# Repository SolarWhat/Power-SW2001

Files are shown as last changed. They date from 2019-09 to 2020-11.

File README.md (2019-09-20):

# Power-SW2001

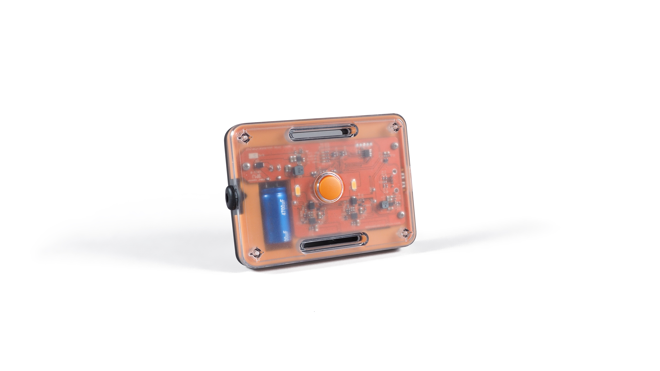
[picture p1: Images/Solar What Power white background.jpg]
Solar What?! Power Hero Image


Solar What?! is the outcome of ongoing research at the University of Edinburgh.

The product design process has taken place over three continents, with input from solar technicians, end users and energy access practitioners.

In 2017 over 6 million small, solar powered lighting devices were sold worldwide and 1.6 million solar powered lighting devices entered electronic waste flows.

We believe that delivering affordable, clean energy for all can also promote responsible production and consumption.

Our goal is to advocate for sustainable design in the global solar industry and promote the repair, reuse and recycling of solar powered electronics. We are pro-solar, anti-waste.

The Solar What?! Power is one of two products we have designed to champion our research and catalyse discussion around sustainability and repairability in the off-grid solar sector. The repository for our other product, the Solar What Light, can be found [here](https://github.com/SolarWhat/Light-SW1001 "here").

We encourage you to download the files, reproduce the products, make edits, suggest improvements and, most importantly, share your ideas around design for sustainable international development.  

More information about the project and the team behind it can be found on our [website](http://www.solarwhat.xyz/index.php "website").

You can get in touch with the team by emailing info@solarwhat.xyz. 

[User Manual and Tech Specs](http://www.solarwhat.xyz/resources.php "User Manual and Tech Specs")

[Gerber Files, BOM and Firmware Files](https://github.com/SolarWhat/Power-SW2001/tree/master/PCB%20Files "Gerber Files, BOM and Firmware Files")

[CAD Files (stp)](https://github.com/SolarWhat/Power-SW2001/blob/master/Solar%20What%20Power%20Assembly.stp "CAD Files (stp)")

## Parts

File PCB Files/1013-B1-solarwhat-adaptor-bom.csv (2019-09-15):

Component | Value | Manufacturer Part Number | Supplier Part Number | Description | Notes
C1 |  | Panasonic ECA1VAM472X | Farnell 8767327
C2 | 1206-10U-35V 10u 35V | 1206 10uF 35V 10% X7R | standard
C3 | 1206-10U-35V 10u 35V | 1206 10uF 35V 10% X7R | standard
C4 | 0805-1U 1u | 0805 1uF 50V 10% X7R | standard
C5 | 0603-100N 100n | 0603 100nF 50V 10% X7R | standard
C6 | 1206-10U-35V 10u 35V | 1206 10uF 35V 10% X7R | standard
C7 | 1206-10U-35V 10u 35V | 1206 10uF 35V 10% X7R | standard
C8 | 1206-10U-35V 10u 35V | 1206 10uF 35V 10% X7R | standard
C9 | 1206-10U-35V 10u 35V | 1206 10uF 35V 10% X7R | standard
C10 | 1206-10U-35V 10u 35V | 1206 10uF 35V 10% X7R | standard
C11 | 1206-10U-35V 10u 35V | 1206 10uF 35V 10% X7R | standard
C12 | 1206-10U-35V 10u 35V | 1206 10uF 35V 10% X7R | standard
C13 | 0603-100N 100n | 0603 100nF 50V 10% X7R | standard
C14 | 1206-10U-35V 10u 35V | 1206 10uF 35V 10% X7R | standard
C15 | 0603-100N 100n | 0603 100nF 50V 10% X7R | standard
C16 | 1206-10U-35V 10u 35V | 1206 10uF 35V 10% X7R | standard
C17 | 1206-10U-35V 10u 35V | 1206 10uF 35V 10% X7R | standard
D1 |  | Cree JB5630AWT-C0-0000-000A0UC430E | Farnell 2853292
D2 |  | Cree JB5630AWT-C0-0000-000A0UC430E | Farnell 2853292
D3 |  | ST STPS1L30U | Farnell 1467550
D4 |  | Vishay VS-10BQ060-M3 | Farnell 2628281
D5 |  | ST STPS1L30U | Farnell 1467550
D6 |  | Red 0603 LED | Farnell 2687488
D7 |  | RB751S40T1G | Farnell 2317437
D8 |  | Green 0603 LED | Farnell 2687486
D9 |  | RB751S40T1G | Farnell 2317437
D10 |  | Green 0603 LED | Farnell 2687486
D11 |  | Orange 0603 LED | Farnell 2687484
D12 |  | RB751S40T1G | Farnell 2317437
D13 |  | RB751S40T1G | Farnell 2317437
D14 |  | RB751S40T1G | Farnell 2317437
D15 |  | RB751S40T1G | Farnell 2317437 |  | fit reversed relative to markings on board revision 1013-B!
D16 |  | RB751S40T1G | Farnell 2317437 |  | fit reversed relative to markings on board revision 1013-B!
J1 |  | Multicomp MC32593 | Farnell 1696534
J2 |  | CamdenBoss CTBP0508/2 | Farnell 2668641
JP1 |  | SOLDER-JUMPER-2MM SOLDER-JUMPER-2MM | - |  | connect
JP2 |  | SOLDER-JUMPER-2MM SOLDER-JUMPER-2MM | - |  | connect
JP3 |  | SOLDER-JUMPER-2MM SOLDER-JUMPER-2MM | - |  | connect
L2 | TDK-VLSX6045EX-220M 22uH | VLS6045EX-220M | Farnell 2493045
L3 | TDK-VLSX5045EX-3R3N 3.3uH | TDK VLS5045EX-3R3N | Farnell 2776741
Q1 |  | Diodes Inc DMP2035U | Farnell 2061419
Q2 |  | Diodes Inc DMP2035U | Farnell 2061419
Q3 |  | Diodes Inc DMP2035U | Farnell 2061419
Q4 |  | Diodes Inc DMP2035U | Farnell 2061419
Q5 |  | Diodes Inc DMP2035U | Farnell 2061419
R1 | 0603-1%-1M 1M | 0603 1M 1% 100mW | standard
R2 | 0603-1%-56K 56K | 0603 56K 1% 100mW | standard
R3 | 0603-1%-10K 10K | 0603 10K 1% 100mW | standard
R4 | 0603-1%-100K 100K | 0603 100K 1% 100mW | standard
R5 | 0603-1%-270K 270K | 0603 270K 1% 100mW | standard
R6 | 0603-1%-2K2 2K2 | 0603 2.2K 1% 100mW | standard
R7 | 0603-1%-47K 47K | 0603 47K 1% 100mW | standard
R8 | 0603-1%-100K 100K | 0603 100K 1% 100mW | standard
R9 | 0603-1%-270K 270K | 0603 270K 1% 100mW | standard
R10 | 0603-1%-2K2 2K2 | 0603 2.2K 1% 100mW | standard
R11 | 0603-1%-100K 100K | 0603 100K 1% 100mW | standard
R12 | 0603-1%-100K 100K | 0603 100K 1% 100mW | standard
R13 | 0603-1%-680K 680K | 0603 680K 1% 100mW | standard
R14 | 0603-1%-100K 100K | 0603 100K 1% 100mW | standard
R15 | 0603-1%-47R 47R | 0603 47R 1% 100mW | standard
R16 | 0805 11R | 0805 11R 1% 100mW | standard
R17 | 0805 1R6 | 0805 1R6 1% 100mW | standard
R18 | 0805 1R6 | 0805 1R6 1% 100mW | standard
R19 | 0603-1%-75K 75K | 0603 75K 1% 100mW | standard
R20 | 0603-1%-49K9 49K9 | 0603 49K9 1% 100mW | standard
R21 | CHIP-0603-DNF DNF |  |  |  | Do Not Populate
R22 | 0603-1%-75K 75K | 0603 75K 1% 100mW | standard
R23 | 0603-1%-49K9 49K9 | 0603 49K9 1% 100mW | standard
R24 | 0603-1%-110K 110K | 0603 110K 1% 100mW | standard
R25 | 0603-1%-1M 1M | 0603 1M 1% 100mW | standard
R26 | 0603-1%-470K 470K | 0603 470K 1% 100mW | standard
R27 | NTC-0603-10K 10K | NCP18XH103F03RB 10K NTC Thermistor | Farnell 2456122
R28 | 0603-1%-470K 470K | 0603 470K 1% 100mW | standard
R29 | NTC-0603-10K 10K | NCP18XH103F03RB 10K NTC Thermistor | Farnell 2456122
R30 | 0603-1%-4K7 4K7 | 0603 4.7K 1% 100mW | standard
R31 | 0603-1%-220R 220R | 0603 220R 1% 100mW | standard
R32 | 0603-1%-220R 220R | 0603 220R 1% 100mW | standard
R33 | 0603-1%-220R 220R | 0603 220R 1% 100mW | standard
R34 | 0603-1%-1M 1M | 0603 1M 1% 100mW | standard
R35 | 0603-1%-220R 220R | 0603 220R 1% 100mW | standard
R36 | 0603-1%-1M 1M | 0603 1M 1% 100mW | standard
R37 | 0603-1%-1M 1M | 0603 1M 1% 100mW | standard
R38 | 0603-1%-1M 1M | 0603 1M 1% 100mW | standard
R39 | 0603-1%-1M 1M | 0603 1M 1% 100mW | standard
R40 | 0603-1%-1M 1M | 0603 1M 1% 100mW | standard
R41 | 0603-1%-1M 1M | 0603 1M 1% 100mW | standard
R42 | CHIP-0603-DNF DNF |  |  |  | Do Not Populate
R43 | CHIP-0603-DNF DNF |  |  |  | Do Not Populate
R44 | 0603-1%-0R 0R | 0603 0R 1% 100mW | standard
R45 | 0603-1%-0R 0R | 0603 0R 1% 100mW | standard
R46 | 0603-1%-0R 0R | 0603 0R 1% 100mW | standard
R47 | 0603-1%-1M 1M | 0603 1M 1% 100mW | standard
R48 | 0603-1%-1M 1M | 0603 1M 1% 100mW | standard
R49 | 0805 11R | 0805 11R 1% 100mW | standard
R50 | 0603-1%-47R 47R | 0603 47R 1% 100mW | standard
SW1 |  | Alcoswitch FSM4JSMA | Farnell 3801305
U1 |  | Microchip MCP16311T-E/MS | Farnell 2857601
U2 |  | MCP73871-2CCI/ML | Farnell 1642489
U3 |  | TI TPS63030 | Farnell 2781754
U4 |  | MCP73871-2CCI/ML | Farnell 1642489
U5 |  | Microchip PIC12F1571-I/SN | Farnell 2419682
U6 |  | MCP1824-ADJ SOT-23-5 | Farnell 1578393
U7 |  | MAX6775XKB+T | Farnell 2799268
U8 |  | MAX6775XKB+T | Farnell 2799268
XBT1 |  | AVX 009155003301006 | Digi-key 478-4687-1-ND
XBT2 |  | AVX 009155003301006 | Digi-key 478-4687-1-ND

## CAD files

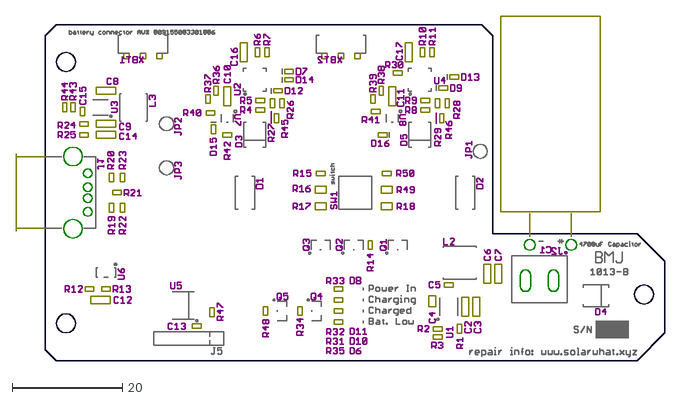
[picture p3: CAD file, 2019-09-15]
PCB Files/1013-B-solarwhat-power-dimensions.dxf
117.8 x 62.5

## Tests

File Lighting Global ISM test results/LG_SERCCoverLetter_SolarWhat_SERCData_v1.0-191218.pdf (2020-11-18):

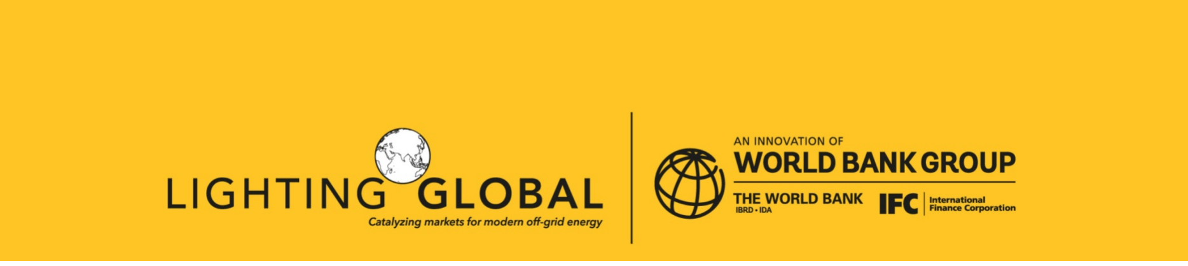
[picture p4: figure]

Lighting Global Quality Test Method Results | 1
Lighting Global Quality Assurance | © Lighting Global 2019

18 December 2019

### Lighting Global Internal Screening Test Method Results: SOLAR WHAT?!

To: Rowan Spear
University of Edinburg
Social Anthropology Chrystal Macmillan Bldg. 15A, George Square, Edinburgh, EH89LD Rowan.spear@ed.ac.uk
From: Lighting Global Quality Assurance Team

We recently received Lighting Global Initial Screening Method (LG-ISM) results for the Solar What?!. The tests were completed at the Schatz Energy Research Center in Arcata, California, and include performance, quality, and attribute measurements. This letter is a summary of the results detailed in the test report, number SERC19002ISM. The three samples arrived at the test lab on 18 August 2019. The sampling report can be provided upon request.

The results indicate that it is likely that your product would not meet the Lighting Global Pico-PV Quality Standards.
1 The reasons the product would likely not meet the standards include issues identified during testing related to truth in advertising, ports, performance reporting, warranty, screw terminals, and water ingress protection. Additional testing according to the Quality Test Method (QTM) procedures described in IEC Technical Specification 62257-9-5 is needed to make an official determination regarding the status of the product in relation to the Lighting Global Quality Standards.
The Lighting Global Pico-PV Quality Standards, which are required for basic program participation, include:
- Truth in Advertising, Performance Reporting and Warranty: Accurate consumer-facing labeling and basic 1-year warranty
- Lumen Maintenance: Average lumen output after 2000 hours of use ≥ 90% initial output or average lumen output after 1000 hours of use ≥ 95% initial output
- Quality: Pass basic durability, safety, and quality checks
- Ingress Protection: Physical ingress protection of IP 2x or greater (IP 3x for separate solar modules and IP 5x for permanently mounted outdoor products)
- Water Protection: Protection from permanent outdoor exposure for outdoor products, frequent rain for portable products with integrated solar modules, and occasional rain for other portable products
- Battery Protection: Protection by an appropriate charge controller that prolongs battery life and protects the safety of the user

Lighting Global Quality Test Method Results | 2
Lighting Global Quality Assurance | © Lighting Global 2019
- Battery Durability: Average battery storage capacity loss ≤ 25% after storage under adverse conditions and no more than one unit of the units tested may have a capacity loss greater than 35%
- Performance Reporting Requirements: Accurately report the product’s light output and solar run time performance for its brightest setting, and if applicable, include a statement regarding the impact of mobile phone charging and/or radio use on the lighting run time

We are providing these test results to you confidentially as a service to your organization so that you can use them to further improve your product. Page 9 contains a list of next steps that will help you to address these issues. Lighting Global does not plan to release the name of your product in conjunction with these results, although we may choose to publish results or derivative analyses in a way that does not reveal the identity of the product. The following is a summary of the test results, drawing from the official test reports that are attached to this letter.

Lighting Global Quality Test Method Results | 3
Lighting Global Quality Assurance | © Lighting Global 2019

## SOLAR WHAT?! Results Summary

Quality Standards

Aspect | Requirement | Results | Notes / Suggested Compliance Actions
Truth in Advertising | Accurate | The full-battery run time for the SW2001 on its high setting is rated 6 h on the product’s website but measured 4.9 h (-18%) The full-battery run time for the SW2001 on its low setting is rated 96 h on the product’s website but measured 53 h (-45%) | Correct the ratings on the website / packaging or change the design of the system to match the ratings.
Ports | Ports must be accurately advertised and meet voltage requirements | The USB Port did not meet the truth-in-advertising or functionality requirements. | Improve the regulation of the 5 V port. See Required Steps for Compliance section for details.
Performance Reporting Requirements | Report light output and solar run time, and include a mobile phone charging statement | The performance reporting for the product could not be evaluated because packaging was not provided. | Provide product packaging for evaluation.
Warranty | 1 year | The warranty could not be evaluated because no warranty information was provided. | Provide a detailed warranty in a consumer-facing location
Lumen Maintenance | L95 or greater at 500 hours | OK | OK
Quality Check | Functionality, wiring, soldering, cables | OK | OK
Circuit and Overload Protection | Sufficient overcurrent and overload protection | OK | OK
Wiring and Connector Safety | Manufacturer declares wires are appropriately sized | OK, with note | Products undergoing QTM testing are required to submit a Lighting Global Off-Grid Product Testing Declaration Form

Lighting Global Quality Test Method Results | 4
Lighting Global Quality Assurance | © Lighting Global 2019
Battery Protection | Protect battery and user Provide safety documentation | OK, with note | Products undergoing QTM testing are required to submit battery safety documentation.
Battery Durability | 25% or less capacity loss, no more than one greater than 35% capacity loss | OK | OK
PV Overvoltage Protection | Sufficient protection from PV voltage when battery removed | OK | OK
Miswiring Protection | Product design sufficiently protects from misconnections | OK | OK
Drop Test Durability | Functionality, safety | OK | OK
Switch, Connector, and Strain Relief Durability | Functionality, safety | OK | OK
Screw Terminal | Adequate tools, materials, and instructions provided, and safety | Adequate instructions are not provided for non-plug and play connections | Provide additional instruction for the non-plug and play connections in a consumer-facing location.
Water Exposure Protection | SW2001:Occasional rain or equivalent | The product does not meet IPX1 and does not have an adequate warning label for ingress protection. | Improve the level of water protection. See Required Steps for Compliance section for details.
| PV module: Permanent outdoor exposure or equivalent | OK | OK
| SW001: Occasional rain or equivalent | The torch does not meet IPX1 and does not have an adequate warning label for ingress protection. | Improve the level of water protection. See Required Steps for Compliance section for details.
Physical Ingress Protection | SW2001 and SW1001: IP 2x | OK, with note | The SW2001 met IP3X and the SW1001 met IP4X
| PV module: IP3x | OK | OK

Lighting Global Quality Test Method Results | 5
Lighting Global Quality Assurance | © Lighting Global 2019

Product Comparison
The box plots below show how the Solar What ?! performs compared to other products that have been tested through the Lighting Global program within the past year for the following metrics:.
Lighting
- lumen maintenance – fraction of total light output remaining after 2000 hours of continuous use
- lumen efficacy – total light output divided by the power consumed by the system
- correlated color temperature – measure of the color appearance of the light; low values are considered warmer and higher values cooler
- color rendering index – measure of the light’s ability to reveal colors on illuminated surfaces
Battery
- battery efficiency – fraction of the energy delivered to the battery during charging that is recovered during use
- battery capacity loss – fraction of the battery capacity irreversibly lost due to degradation of the battery after a simulated six-month storage period
Ports and Charging
- ports efficiency – fraction of energy from the appliance port that is delivered to the appliance when powered on
- solar operation efficiency – ratio of the energy produced by the solar module during a typical day of solar charging to the energy that could be produced (i.e., if the module operated at the maximum power point at all times)
- charging efficiency – fraction of the energy input into the charging port that is delivered to the battery
In each box plot, the center horizontal line represents the median value of the performance metric for products that have been tested within the past year. The box includes the values between the first and third quartiles (i.e., the middle 50%). The ends of the whiskers show the minimum and maximum values observed. The red X represents the Solar What?!’s performance.

Lighting Global Quality Test Method Results | 6

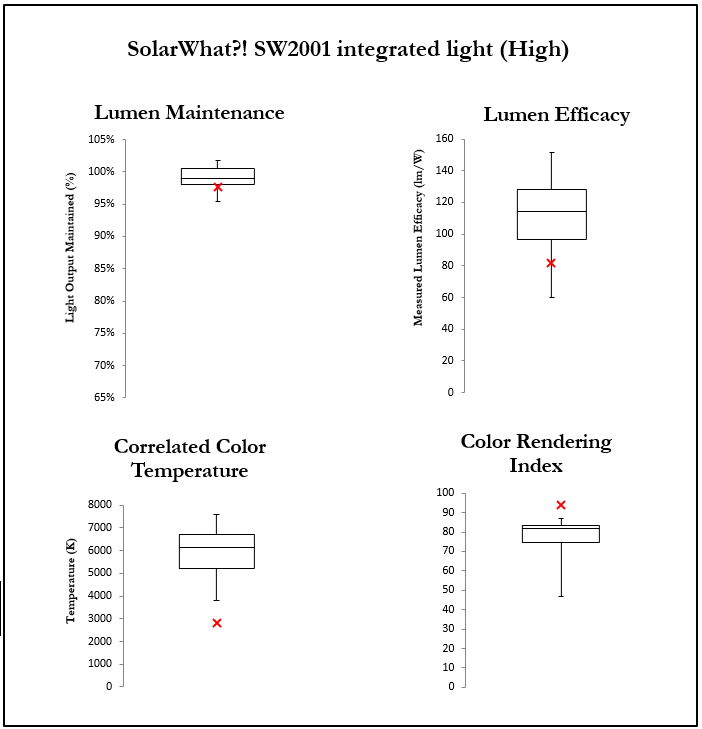
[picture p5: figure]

Lighting Global Quality Assurance | © Lighting Global 2019

Lighting Global Quality Test Method Results | 7

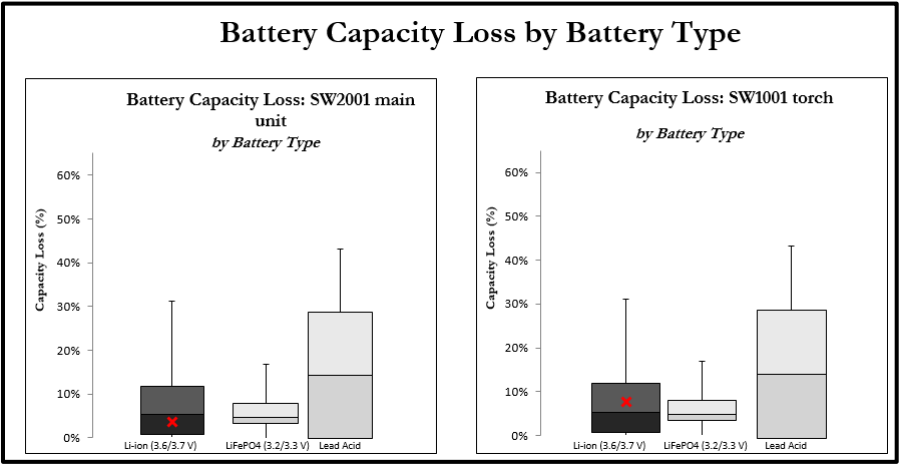
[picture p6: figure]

Lighting Global Quality Assurance | © Lighting Global 2019
- The lumen efficacy of the Solar What?! SW2001 is notably low compared to other products that have been tested through the Lighting Global program within the past year. A lower lumen efficacy indicates that your product’s LED and driver require more power to provide light compared to other products tested. You may consider improving the energy efficiency of the main control unit and light bulbs. This could allow the product to provide a brighter light or longer run time using the existing solar module and battery.
- The correlated color temperature (CCT) of the Solar What?! SW2001 is notably low compared to other products that have been tested through the Lighting Global program within the past year. A lower CCT indicates that the light produced by your product is warmer (more red) compared to other products tested. Consumer preferences regarding light color vary, and there is no consensus on the ideal CCT value for off-grid solar lamps. Nonetheless, some market studies indicate that many consumers prefer products with lower CCT values (i.e. warmer light). Research regarding CCT and eye safety indicates that very bright lights with high CCT can increase the risk of hazard to the human eye. See Lighting Global Eco-Design Notes Issue 5: LED Lights and Eye Safety Part II: Blue light hazards via www.lightingglobal.org/resources/?fwp_resource_type=eco-design-notes.
- The color rendering index (CRI) of the Solar What?! SW2001 is notably high compared to other products that have been tested through the Lighting Global program within the past year. A higher CRI indicates that your product’s LED package is able to reveal colors better compared to other products tested; that is, colors more closely resemble their appearance under daylight or an incandescent lamp.

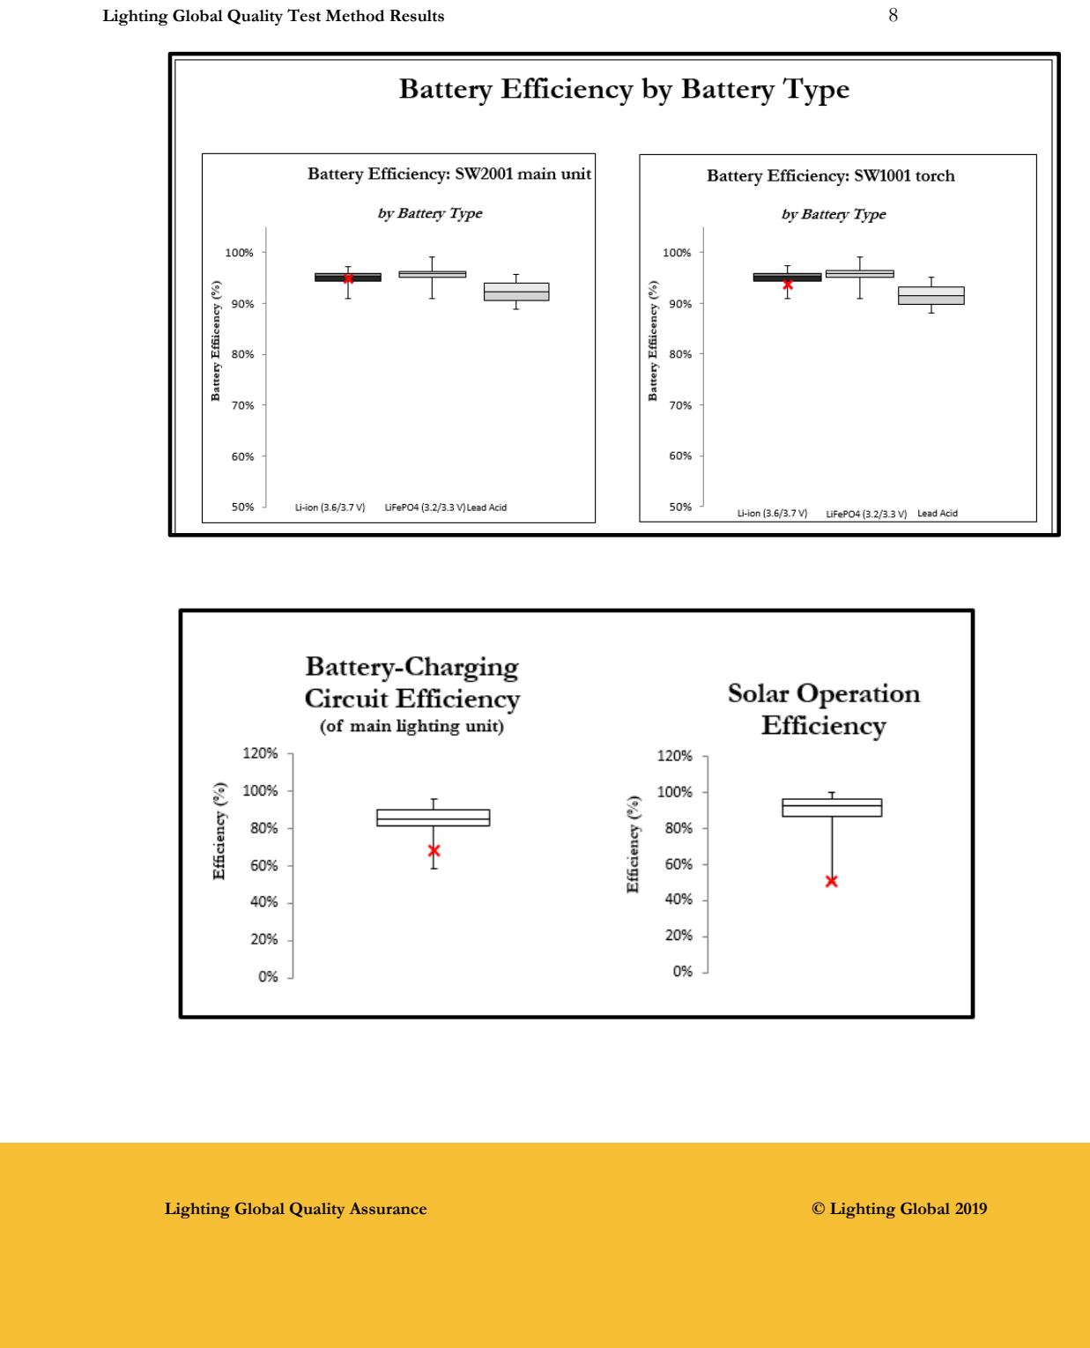
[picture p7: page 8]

Lighting Global Quality Test Method Results | 8
Lighting Global Quality Assurance | © Lighting Global 2019

Lighting Global Quality Test Method Results | 9
Lighting Global Quality Assurance | © Lighting Global 2019
- The battery-charging circuit efficiency of the Solar What?! SW2001 is notably low compared to other products that have been tested through the Lighting Global program within the past year. A lower charging efficiency indicates that the charging circuitry within the product, delivering energy from the generator to the battery, is less efficient than other products tested.
- The solar operation efficiency of the Solar What?! is notably low compared to other products that have been tested through the Lighting Global program within the past year. A lower solar operation efficiency indicates that your product is less effectively utilizing its solar module compared to other products tested. Product Strengths
- The product is well constructed, and the workmanship is good.
- The Solar What?! maintains its luminous output over 500 hours of continuous use.
- The housing appears to be sturdy.

Required Steps for Compliance
- Properly rate the product’s full-battery run time in all consumer-facing locations. The full-battery run time for the SW2001 on its high setting is rated 6 h on the product’s website but measured 4.9 h (-18%). The full-battery run time for the SW2001 on its low setting is rated 96 h on the product’s website but measured 53 h (-45%).
- Properly rate the current of the USB port. Currently the port is rated to deliver up to 5 A, but the measured maximum current was 0.36 A.
- Include a consumer-facing warranty of at least 1 year for all product components, including the product’s battery. The warranty must include information regarding the terms of the warranty and how to access the warranty. Details of the warranty requirements are available here: http://www.lightingglobal.org/resource/performance-reporting-requirements/
- Improve the voltage regulation of the USB ports. These ports must meet the voltage requirements listed in footnote d of the Pico PV Quality Standards. The product does not meet the Standard for USB port functionality because its USB port voltage is outside the allowable thresholds. The Standards require that the USB port not fall below 4.5 V and never exceed 5.5 V under all test conditions, except the deep discharge protection voltage (USB voltages of 4.25 V are permitted when the product’s battery has reached the deep discharge protection cutoff). The Solar What’s USB port voltage falls below the proposed requirement; falling to 4.37 V. The current for the USB port is rated 0.5 A, but measured 0.36 and therefore does not meet the truth-in-advertising requirement for ports. Redesign the port regulation so that it functions within the allowable threshold at high battery voltages.
- Improve the level of water protection for the SW1001 and the SW2001. As portable separate products, the product must have water protection against occasional rain. This could be achieved using one of three options:
- Meet IPX1 – vertical water drip. This could be done by adding gaskets, improving jack positioning, covering jacks, and/or reducing manufacturing tolerances.
- Include an appropriate consumer-facing warning label to keep the product from water exposure. The warning label must explain the degree of protection from water provided by the product (e.g., “Designed for indoor use”) AND steps a consumer should take to prevent water exposure and to drain or dry the product (e.g., “Protect the product from exposure to water. If the product gets wet, …”)
- OR include a technical level of water protection, such as a conformal coating and a proper water removal strategy.

Lighting Global Quality Test Method Results | 10
Lighting Global Quality Assurance | © Lighting Global 2019
- Report the product’s light output and solar run time for the brightest setting and include a statement regarding the impact of mobile phone charging on lighting run time on the product packaging. Detailed guidelines are described in the Performance Reporting Requirements Policy here: http://www.lightingglobal.org/resource/performance-reporting-requirements/
- The product does not meet the requirements for screw terminals for the following reasons:
- Adequate instructions for making the connections, a list of required tools, information regarding the type of battery and size of PV module to be used with the product, and adequate description for identifying wires to avoid incorrect connections were not provided in writing with the product. This information is provided in the on-line user manual, but must be available in writing in order to meet the requirements.
- There are no evident physical barriers on the screw terminal block to prevent short-circuiting the PV leads. The Lighting Global Standards require short circuit protection for the leads from the battery to PV module.
- There is no statement reporting that the terminals are for indoor use only provided in writing nor provided on the product’s website.
Next Steps
- Because the ISM results indicate that the Solar What?! is unlikely meet the Quality Standards, we
recommend that you take action to bring your product in line with the Quality Standards. The key points of failure for not meeting the Quality Standards are summarized above. Once these changes have been made, we suggest you coordinate with the Lighting Global Quality Assurance Team to submit the Solar What?! for testing according to the Quality Test Method (QTM) approach.

In addition, Lighting Global has produced a series of technical notes and eco design notes on off-grid lighting that you may find helpful going forward; they are available at: http://www.lightingglobal.org/resources/?fwp_resource_type=technical-notes
and
http://www.lightingglobal.org/resources/?fwp_resource_type=eco-design-notes
We are always looking for feedback on the Lighting Global Quality Assurance process and framework. If you found these results helpful, please write to tell us how you plan to use them.
-Lighting Global Quality Assurance Team

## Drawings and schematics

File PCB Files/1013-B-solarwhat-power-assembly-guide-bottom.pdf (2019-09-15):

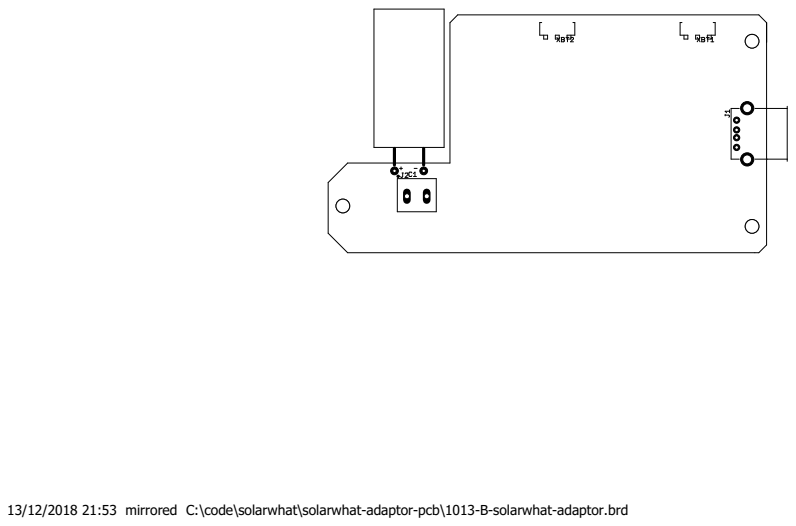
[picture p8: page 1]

13/12/2018 21:53 mirrored C:\code\solarwhat\solarwhat-adaptor-pcb\1013-B-solarwhat-adaptor.brd

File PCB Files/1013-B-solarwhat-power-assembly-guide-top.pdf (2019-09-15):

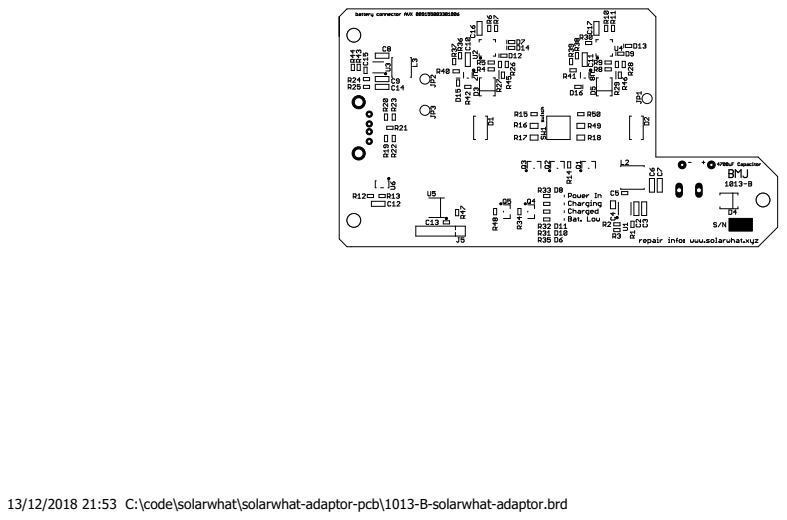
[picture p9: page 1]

13/12/2018 21:53 C:\code\solarwhat\solarwhat-adaptor-pcb\1013-B-solarwhat-adaptor.brd

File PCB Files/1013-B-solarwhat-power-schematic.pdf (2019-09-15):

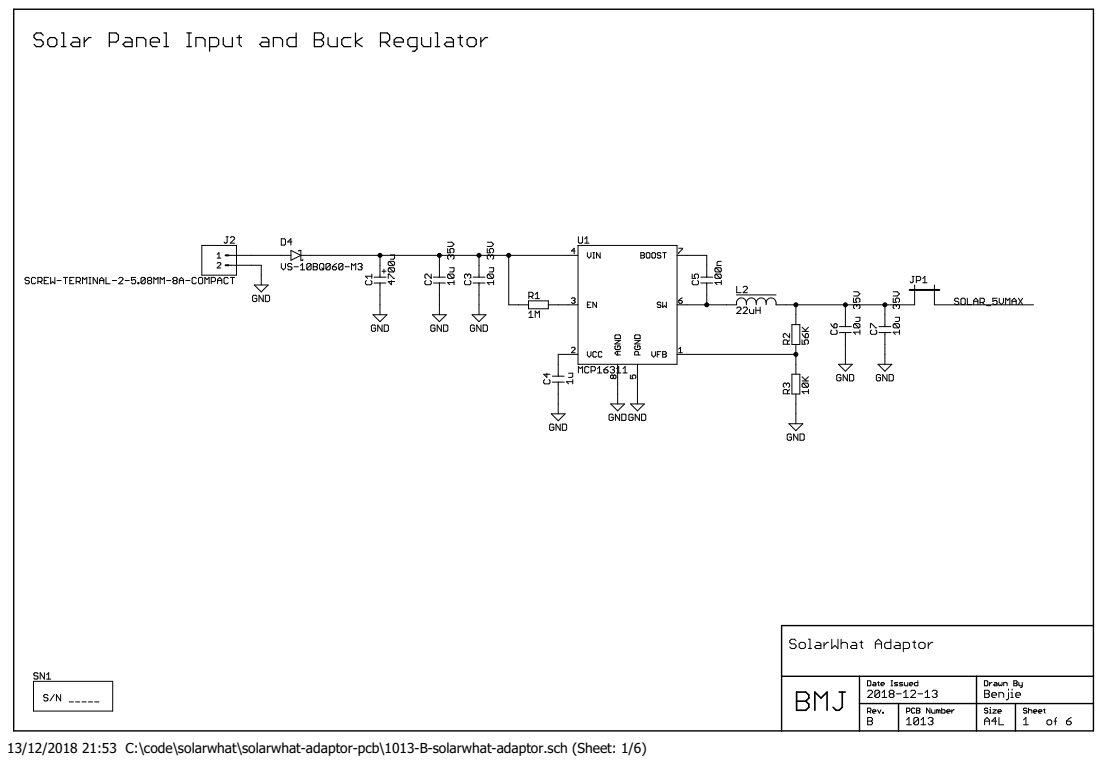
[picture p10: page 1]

13/12/2018 21:53 C:\code\solarwhat\solarwhat-adaptor-pcb\1013-B-solarwhat-adaptor.sch (Sheet: 1/6)

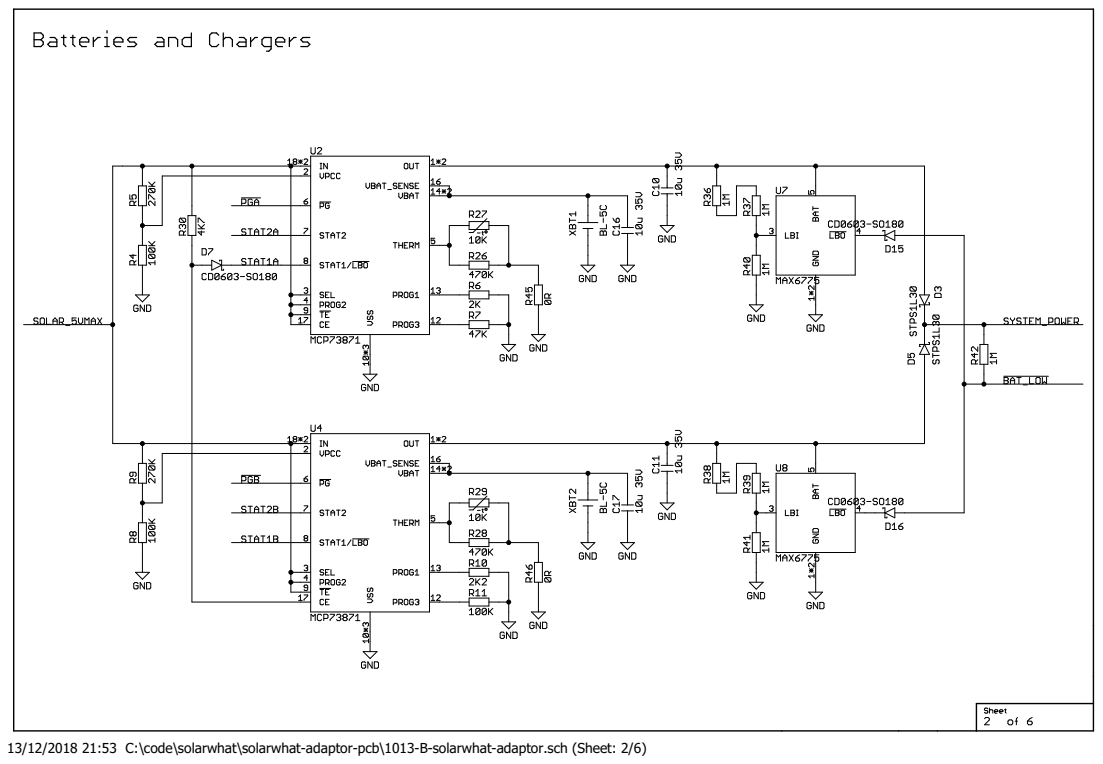
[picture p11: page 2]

13/12/2018 21:53 C:\code\solarwhat\solarwhat-adaptor-pcb\1013-B-solarwhat-adaptor.sch (Sheet: 2/6)

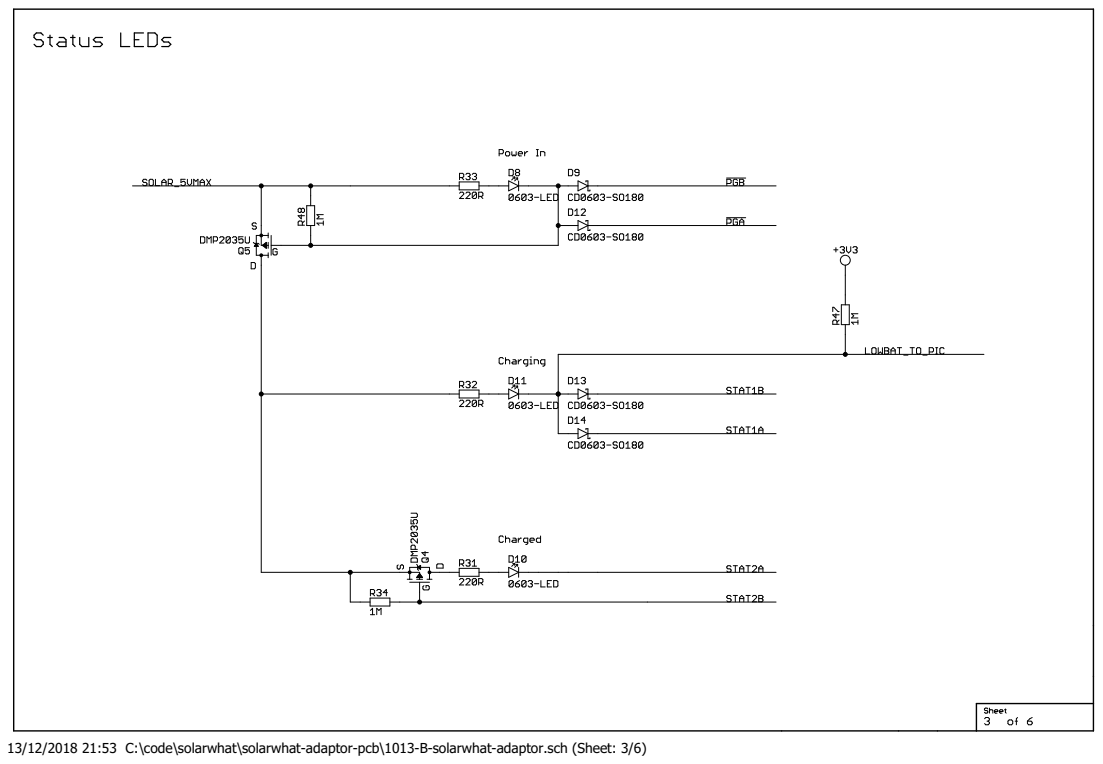
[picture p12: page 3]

13/12/2018 21:53 C:\code\solarwhat\solarwhat-adaptor-pcb\1013-B-solarwhat-adaptor.sch (Sheet: 3/6)

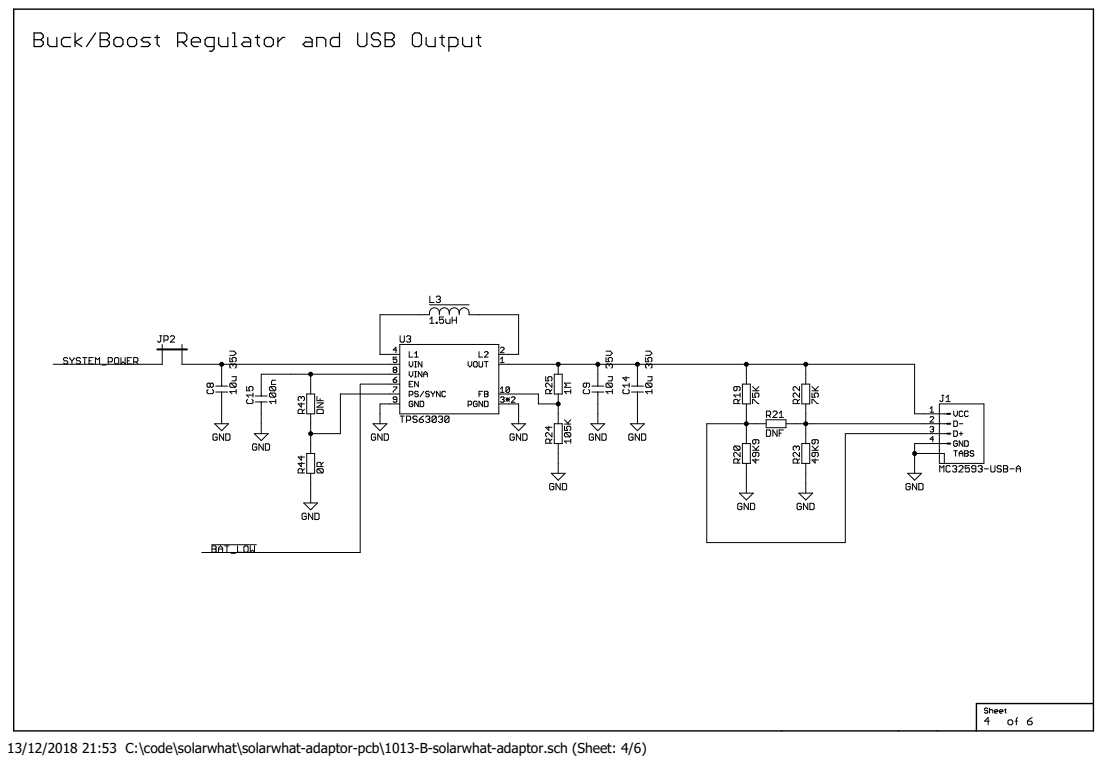
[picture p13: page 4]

13/12/2018 21:53 C:\code\solarwhat\solarwhat-adaptor-pcb\1013-B-solarwhat-adaptor.sch (Sheet: 4/6)

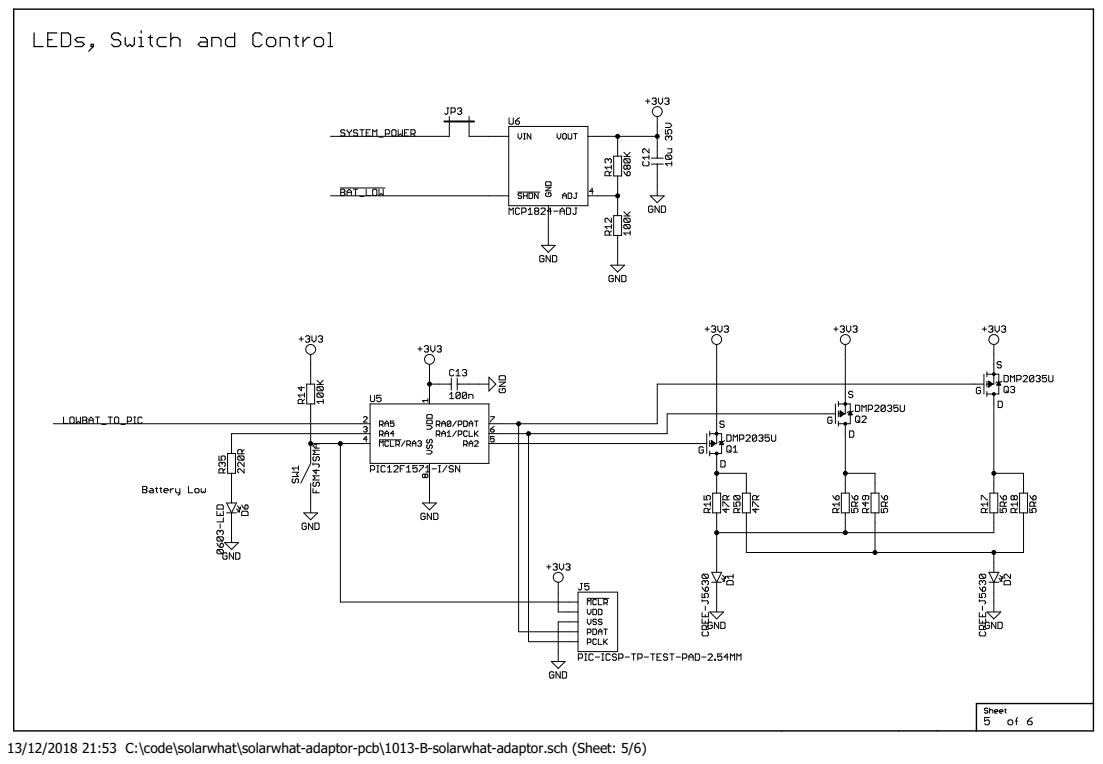
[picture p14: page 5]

13/12/2018 21:53 C:\code\solarwhat\solarwhat-adaptor-pcb\1013-B-solarwhat-adaptor.sch (Sheet: 5/6)

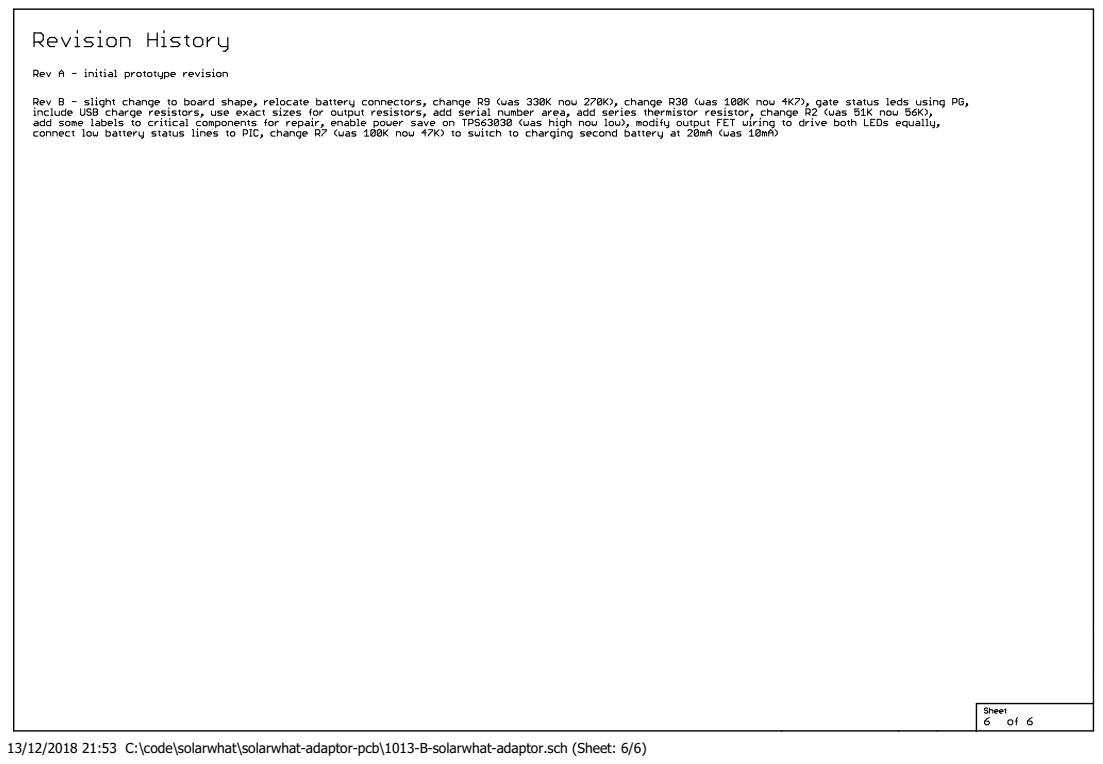
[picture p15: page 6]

13/12/2018 21:53 C:\code\solarwhat\solarwhat-adaptor-pcb\1013-B-solarwhat-adaptor.sch (Sheet: 6/6)

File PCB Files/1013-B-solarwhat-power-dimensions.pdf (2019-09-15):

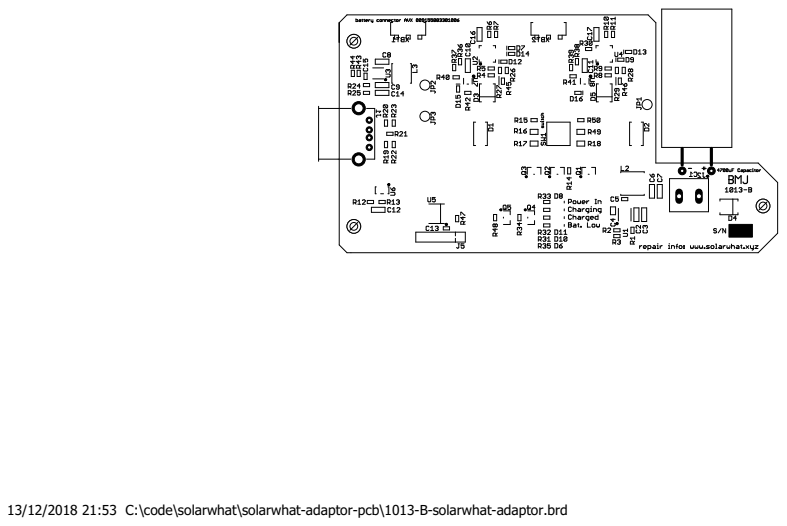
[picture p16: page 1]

13/12/2018 21:53 C:\code\solarwhat\solarwhat-adaptor-pcb\1013-B-solarwhat-adaptor.brd

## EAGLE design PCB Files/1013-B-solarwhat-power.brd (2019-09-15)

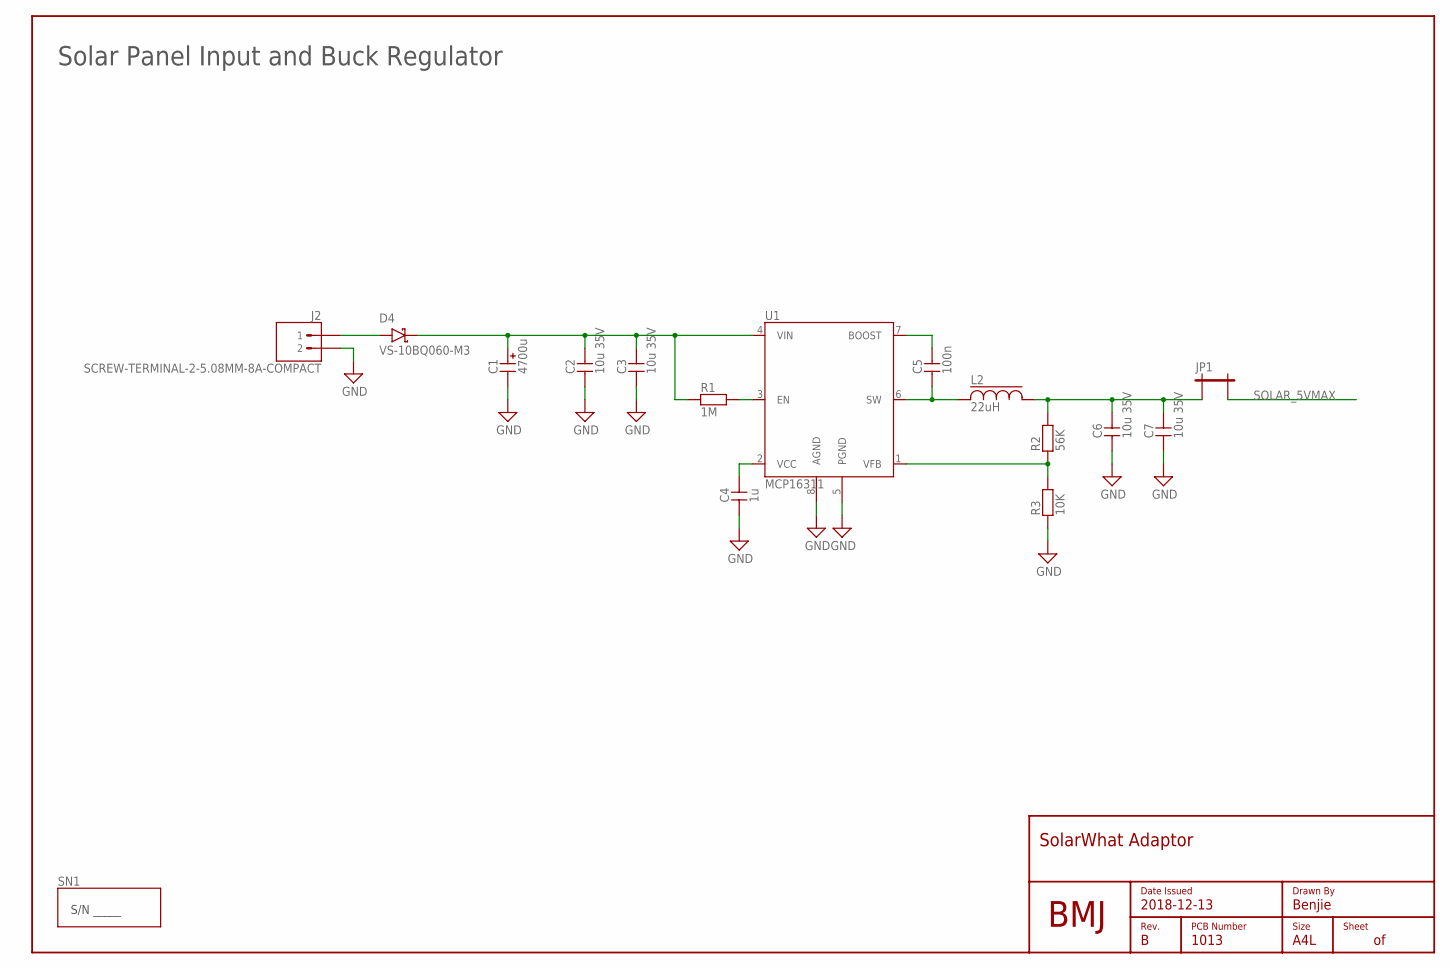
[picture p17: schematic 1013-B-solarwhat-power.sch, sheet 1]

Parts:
C1: 4700u; 18X36-TH-FLAT
C2, C3, C6, C7: 10u 35V; 1206
C4: 1u; 0805
C5: 100n; 0603
D4: VS-10BQ060-M3; SMB-ST
FRAME1: A4L-NEW; PCB-ID
J2: SCREW-TERMINAL-2-5.08MM-8A-COMPACT; CTBP0508/2
JP1: SOLDER-JUMPER-2MM
L2: 22uH; TDK-VLSX6045EX
LOGO1: BMJ-LOGO
R1: 1M; 0603
R2: 56K; 0603
R3: 10K; 0603
SN1: SERIAL-NUMBER-AREA; SERIAL-NUMBER-AREA-SMALL
U1: MCP16311; MSOP-8

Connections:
GND: C1.-, C2.1, C3.1, C4.1, C6.1, C7.1, J2.2, R3.1, U1.5 (PGND), U1.8 (AGND); also elsewhere on the board
unnamed: R1.2, U1.3 (EN)
unnamed: C1.+, C2.2, C3.2, D4.K (C), R1.1, U1.4 (VIN)
unnamed: C4.2, U1.2 (VCC)
unnamed: C5.2, U1.7 (BOOST)
unnamed: C5.1, L2.1, U1.6 (SW)
unnamed: D4.A, J2.1
unnamed: R2.1, R3.2, U1.1 (VFB)
unnamed: C6.2, C7.2, JP1.1, L2.2, R2.2
SOLAR_5VMAX: JP1.2; also elsewhere on the board

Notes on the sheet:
Solar Panel Input and Buck Regulator

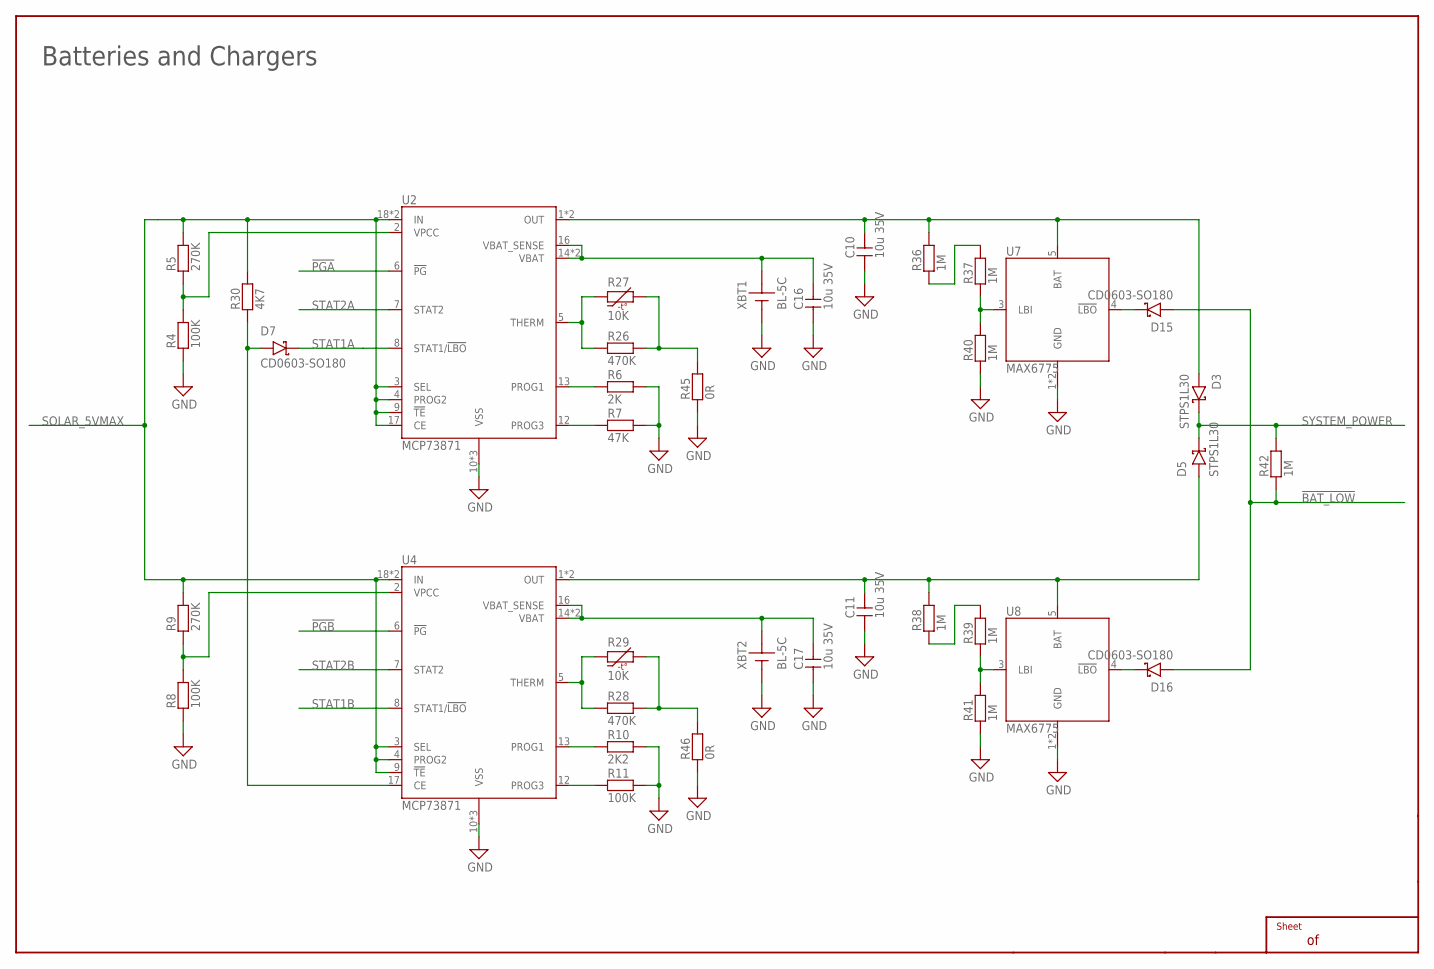
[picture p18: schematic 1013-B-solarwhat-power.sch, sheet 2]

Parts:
C10, C11, C16, C17: 10u 35V; 1206
D3, D5: STPS1L30; SMB-ST
D7, D15, D16: CD0603-SO180; 0603
FRAME2: A4L-CONTINUATION; EMPTY
R4, R8, R11: 100K; 0603
R5, R9: 270K; 0603
R6: 2K; 0603
R7: 47K; 0603
R10: 2K2; 0603
R26, R28: 470K; 0603
R27, R29: 10K; 0603
R30: 4K7; 0603
R36, R37, R38, R39, R40, R41, R42: 1M; 0603
R45, R46: 0R; 0603
U2, U4: MCP73871; QFN-20
U7, U8: MAX6775; SC70
XBT1, XBT2: BL-5C; 3MM-BATTERY-3WAY

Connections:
!BAT_LOW: D15.A, D16.A, R42.1; also elsewhere on the board
!PGA: U2.6 (!PG); also elsewhere on the board
!PGB: U4.6 (!PG); also elsewhere on the board
GND: C10.1, C11.1, C16.1, C17.1, R4.1, R6.2, R7.2, R8.1, R10.2, R11.2, R40.1, R41.1, R45.1, R46.1, U2.10 (VSS), U2.11 (VSS), U2.PAD (VSS), U4.10 (VSS), U4.11 (VSS), U4.PAD (VSS), U7.1 (GND), U7.2 (GND), U8.1 (GND), U8.2 (GND), XBT1.-, XBT2.-; also elsewhere on the board
unnamed: R4.2, R5.1, U2.2 (VPCC)
unnamed: R6.1, U2.13 (PROG1)
unnamed: R7.1, U2.12 (PROG3)
unnamed: C16.2, U2.14 (VBAT), U2.15 (VBAT), U2.16 (VBAT_SENSE), XBT1.+
unnamed: C10.2, D3.A, R36.2, U2.1 (OUT), U2.20 (OUT), U7.5 (BAT)
unnamed: R8.2, R9.1, U4.2 (VPCC)
unnamed: R10.1, U4.13 (PROG1)
unnamed: R11.1, U4.12 (PROG3)
unnamed: C17.2, U4.14 (VBAT), U4.15 (VBAT), U4.16 (VBAT_SENSE), XBT2.+
unnamed: C11.2, D5.A, R38.2, U4.1 (OUT), U4.20 (OUT), U8.5 (BAT)
unnamed: D7.A, R30.1, U4.17 (CE)
unnamed: R26.1, R27.1, U2.5 (THERM)
unnamed: R28.1, R29.1, U4.5 (THERM)
unnamed: R36.1, R37.2
unnamed: R37.1, R40.2, U7.3 (LBI)
unnamed: R38.1, R39.2
unnamed: R39.1, R41.2, U8.3 (LBI)
unnamed: D15.K (C), U7.4 (!LBO)
unnamed: D16.K (C), U8.4 (!LBO)
unnamed: R26.2, R27.2, R45.2
unnamed: R28.2, R29.2, R46.2
SOLAR_5VMAX: R5.2, R9.2, R30.2, U2.3 (SEL), U2.4 (PROG2), U2.9 (!TE), U2.17 (CE), U2.18 (IN), U2.19 (IN), U4.3 (SEL), U4.4 (PROG2), U4.9 (!TE), U4.18 (IN), U4.19 (IN); also elsewhere on the board
STAT1A: D7.K (C), U2.8 (STAT1/!LBO); also elsewhere on the board
STAT1B: U4.8 (STAT1/!LBO); also elsewhere on the board
STAT2A: U2.7 (STAT2); also elsewhere on the board
STAT2B: U4.7 (STAT2); also elsewhere on the board
SYSTEM_POWER: D3.K (C), D5.K (C), R42.2; also elsewhere on the board

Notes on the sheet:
Batteries and Chargers

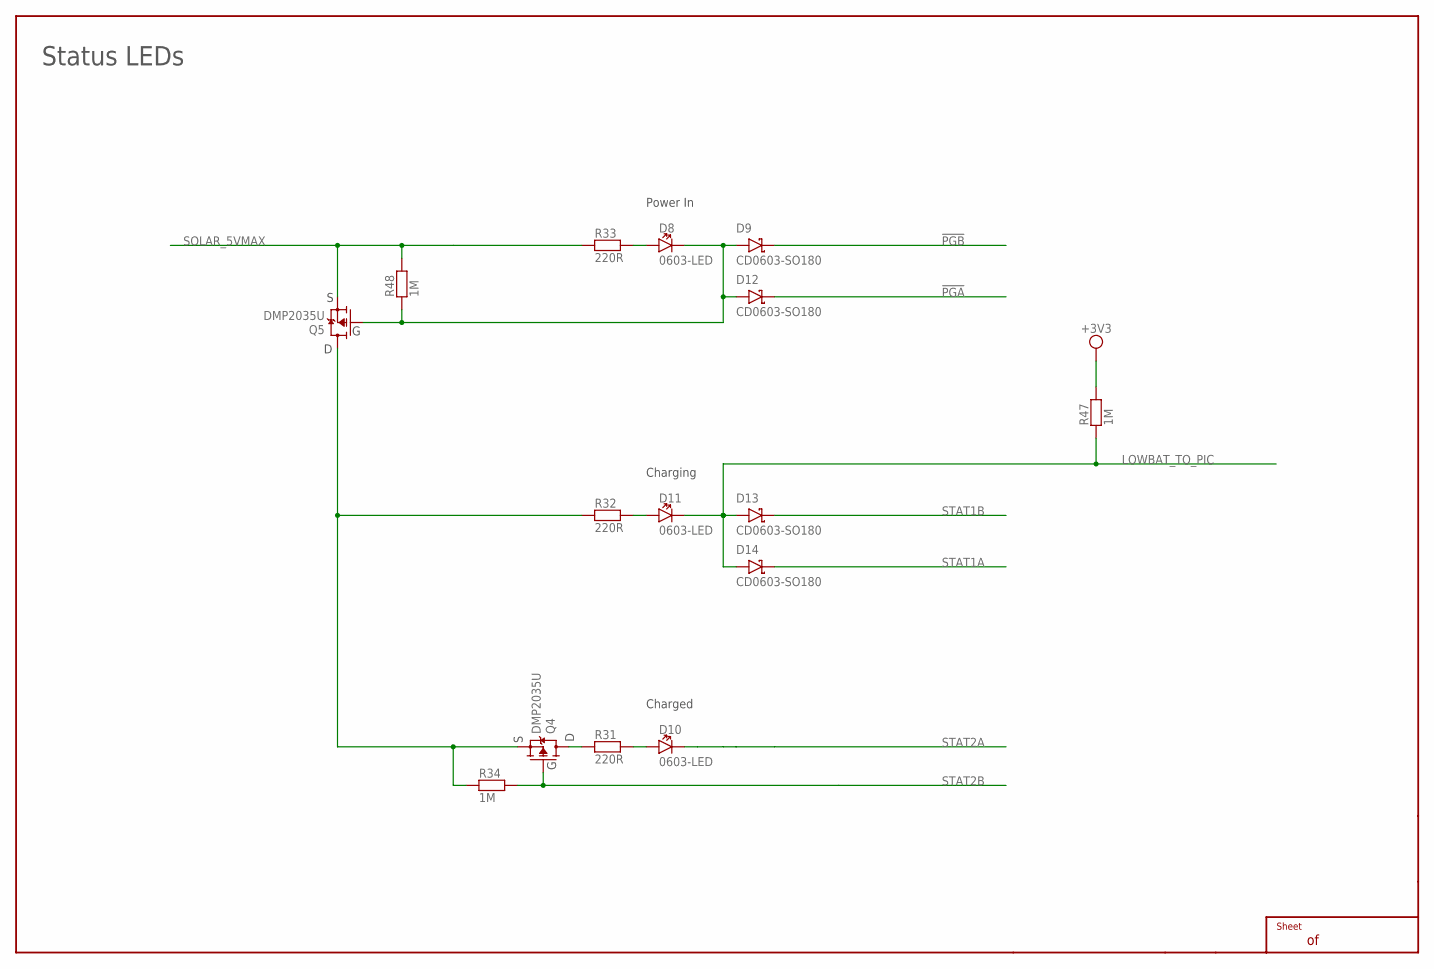
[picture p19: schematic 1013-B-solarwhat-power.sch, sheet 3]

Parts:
D8, D10, D11: 0603-LED
D9, D12, D13, D14: CD0603-SO180; 0603
FRAME5: A4L-CONTINUATION; EMPTY
Q4, Q5: DMP2035U; SOT-23
R31, R32, R33: 220R; 0603
R34, R47, R48: 1M; 0603

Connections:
!PGA: D12.K (C); also elsewhere on the board
!PGB: D9.K (C); also elsewhere on the board
+3V3: R47.2; also elsewhere on the board
GATED-LED-POWER: Q4.2 (S), Q5.3 (D), R32.1, R34.1
LOWBAT_TO_PIC: D11.C, D13.A, D14.A, R47.1; also elsewhere on the board
unnamed: D8.C, D9.A, D12.A, Q5.1 (G), R48.1
unnamed: Q4.3 (D), R31.1
unnamed: D10.A, R31.2
unnamed: D11.A, R32.2
unnamed: D8.A, R33.2
SOLAR_5VMAX: Q5.2 (S), R33.1, R48.2; also elsewhere on the board
STAT1A: D14.K (C); also elsewhere on the board
STAT1B: D13.K (C); also elsewhere on the board
STAT2A: D10.C; also elsewhere on the board
STAT2B: Q4.1 (G), R34.2; also elsewhere on the board

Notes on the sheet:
Power In
Charging
Charged
Status LEDs

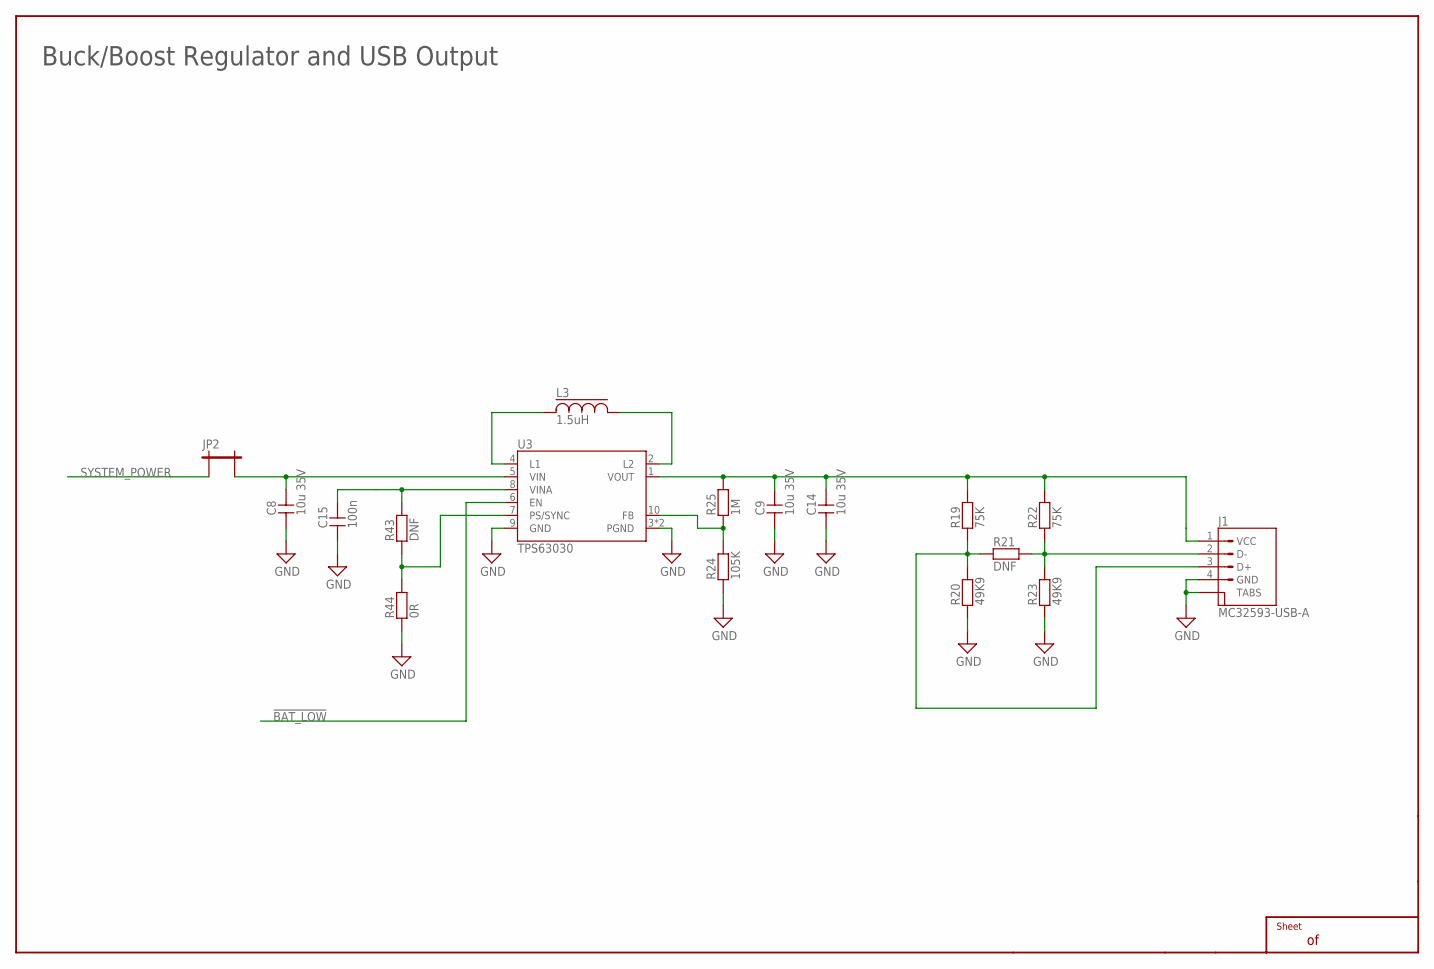
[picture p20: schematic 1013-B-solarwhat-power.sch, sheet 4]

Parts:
C8, C9, C14: 10u 35V; 1206
C15: 100n; 0603
FRAME3: A4L-CONTINUATION; EMPTY
J1: MC32593-USB-A; MC32593
JP2: SOLDER-JUMPER-2MM
L3: 1.5uH; TDK-VLSX5045EX
R19, R22: 75K; 0603
R20, R23: 49K9; 0603
R21, R43: DNF; 0603
R24: 105K; 0603
R25: 1M; 0603
R44: 0R; 0603
U3: TPS63030; VSON-10

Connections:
!BAT_LOW: U3.6 (EN); also elsewhere on the board
GND: C8.1, C9.1, C14.1, C15.1, J1.4 (GND), J1.TAB1 (TABS), J1.TAB2 (TABS), R20.1, R23.1, R24.1, R44.1, U3.3 (PGND), U3.9 (GND), U3.PAD (PGND); also elsewhere on the board
unnamed: J1.2 (D-), R21.2, R22.1, R23.2
unnamed: J1.3 (D+), R19.1, R20.2, R21.1
unnamed: L3.1, U3.4 (L1)
unnamed: L3.2, U3.2 (L2)
unnamed: C15.2, R43.2, U3.8 (VINA)
unnamed: R24.2, R25.1, U3.10 (FB)
unnamed: C9.2, C14.2, J1.1 (VCC), R19.2, R22.2, R25.2, U3.1 (VOUT)
unnamed: C8.2, JP2.2, U3.5 (VIN)
unnamed: R43.1, R44.2, U3.7 (PS/SYNC)
SYSTEM_POWER: JP2.1; also elsewhere on the board

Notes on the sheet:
Buck/Boost Regulator and USB Output

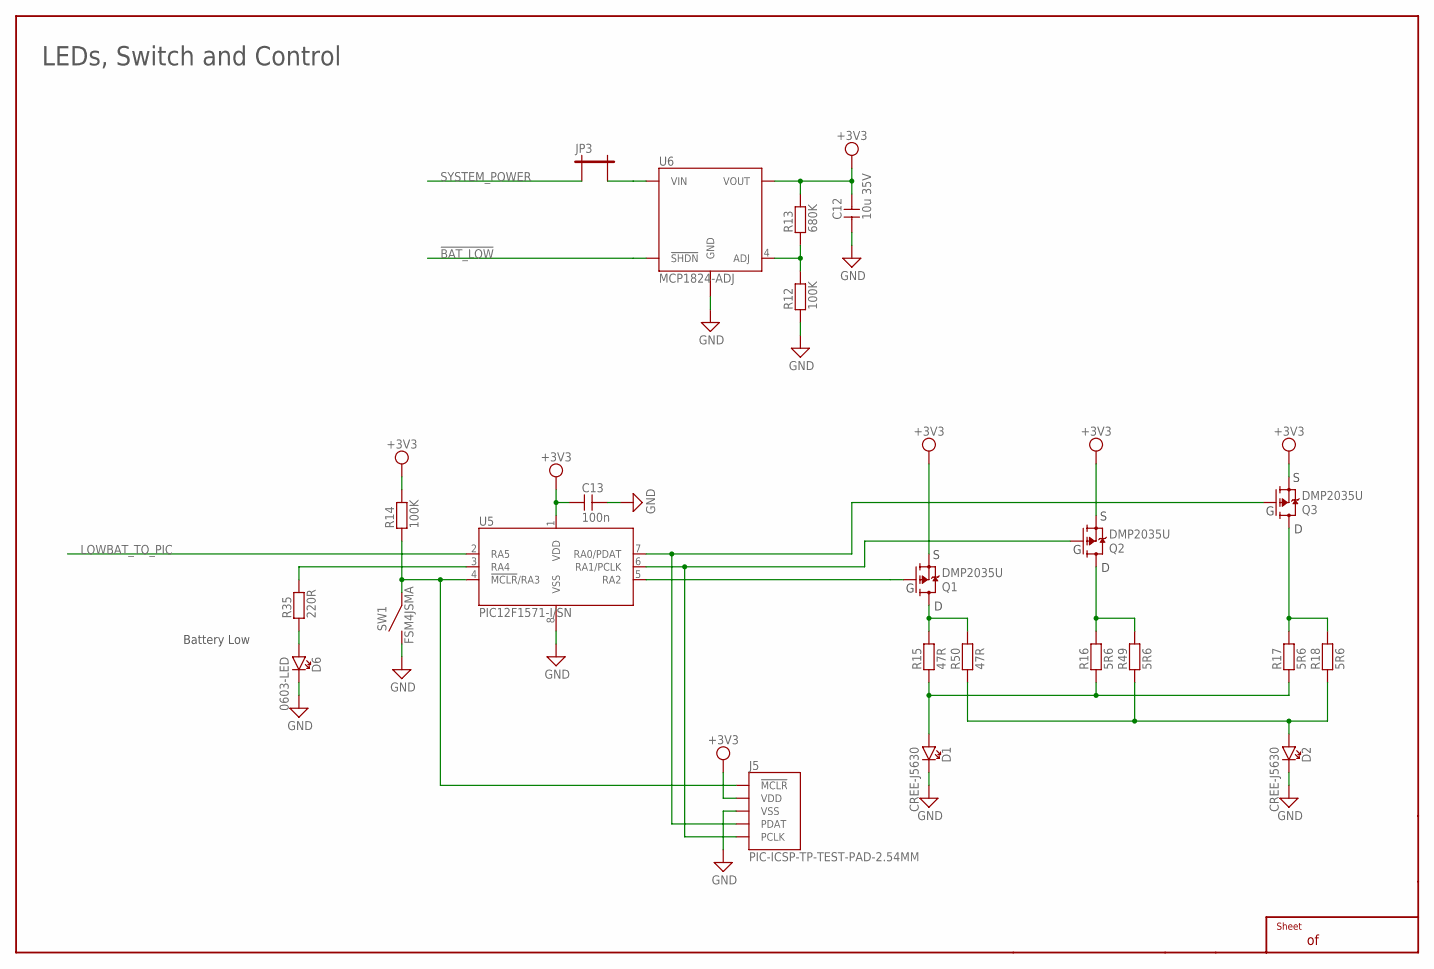
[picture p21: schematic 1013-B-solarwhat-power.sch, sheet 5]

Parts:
C12: 10u 35V; 1206
C13: 100n; 0603
D1, D2: CREE-J5630
D6: 0603-LED
FRAME4: A4L-CONTINUATION; EMPTY
J5: PIC-ICSP-TP-TEST-PAD-2.54MM; PIC-ICSP-TEST-PAD-2.54MM
JP3: SOLDER-JUMPER-2MM
Q1, Q2, Q3: DMP2035U; SOT-23
R12, R14: 100K; 0603
R13: 680K; 0603
R15, R50: 47R; 0603
R16, R17, R18, R49: 5R6; 0805
R35: 220R; 0603
SW1: FSM4JSMA; ALCOSWITCH-FSM4JSMA
U5: PIC12F1571-I/SN; SOIC-8
U6: MCP1824-ADJ; SOT-23-5

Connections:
!BAT_LOW: U6.3 (!SHDN); also elsewhere on the board
+3V3: C12.2, C13.1, J5.V+ (VDD), Q1.2 (S), Q2.2 (S), Q3.2 (S), R13.2, R14.2, U5.1 (VDD), U6.5 (VOUT); also elsewhere on the board
GND: C12.1, C13.2, D1.K (C), D2.K (C), D6.C, J5.GND (VSS), R12.1, SW1.1@1, SW1.1@2, U5.8 (VSS), U6.2 (GND); also elsewhere on the board
LOWBAT_TO_PIC: U5.2 (RA5); also elsewhere on the board
unnamed: J5.VPP (!MCLR), R14.1, SW1.2@1, SW1.2@2, U5.4 (!MCLR!/RA3)
unnamed: R12.2, R13.1, U6.4 (ADJ)
unnamed: D1.A, R15.1, R16.1, R17.1
unnamed: Q1.3 (D), R15.2, R50.2
unnamed: Q2.3 (D), R16.2, R49.2
unnamed: Q3.3 (D), R17.2, R18.2
unnamed: D2.A, R18.1, R49.1, R50.1
unnamed: J5.DAT, Q3.1 (G), U5.7 (RA0/PDAT)
unnamed: J5.CLK, Q2.1 (G), U5.6 (RA1/PCLK)
unnamed: Q1.1 (G), U5.5 (RA2)
unnamed: R35.2, U5.3 (RA4)
unnamed: JP3.2, U6.1 (VIN)
unnamed: D6.A, R35.1
SYSTEM_POWER: JP3.1; also elsewhere on the board

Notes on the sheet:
LEDs, Switch and Control
Battery Low

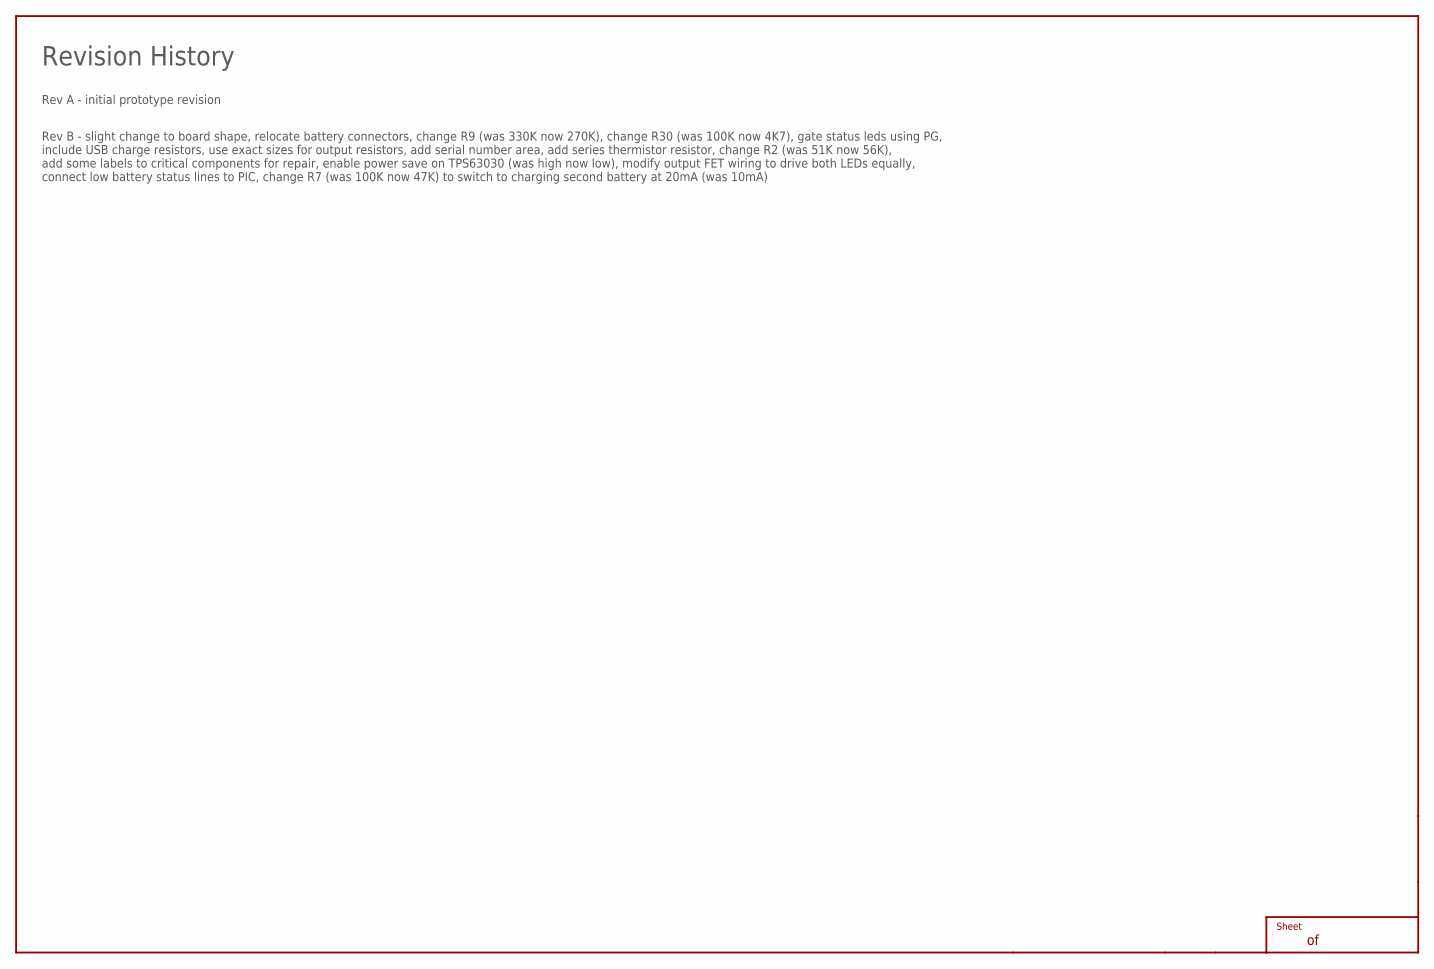
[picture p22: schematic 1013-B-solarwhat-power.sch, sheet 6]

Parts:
FRAME6: A4L-CONTINUATION; EMPTY

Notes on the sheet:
Revision History
Rev A - initial prototype revision
Rev B - slight change to board shape, relocate battery connectors, change R9 (was 330K now 270K), change R30 (was 100K now 4K7), gate status leds using PG, include USB charge resistors, use exact sizes for output resistors, add serial number area, add series thermistor resistor, change R2 (was 51K 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

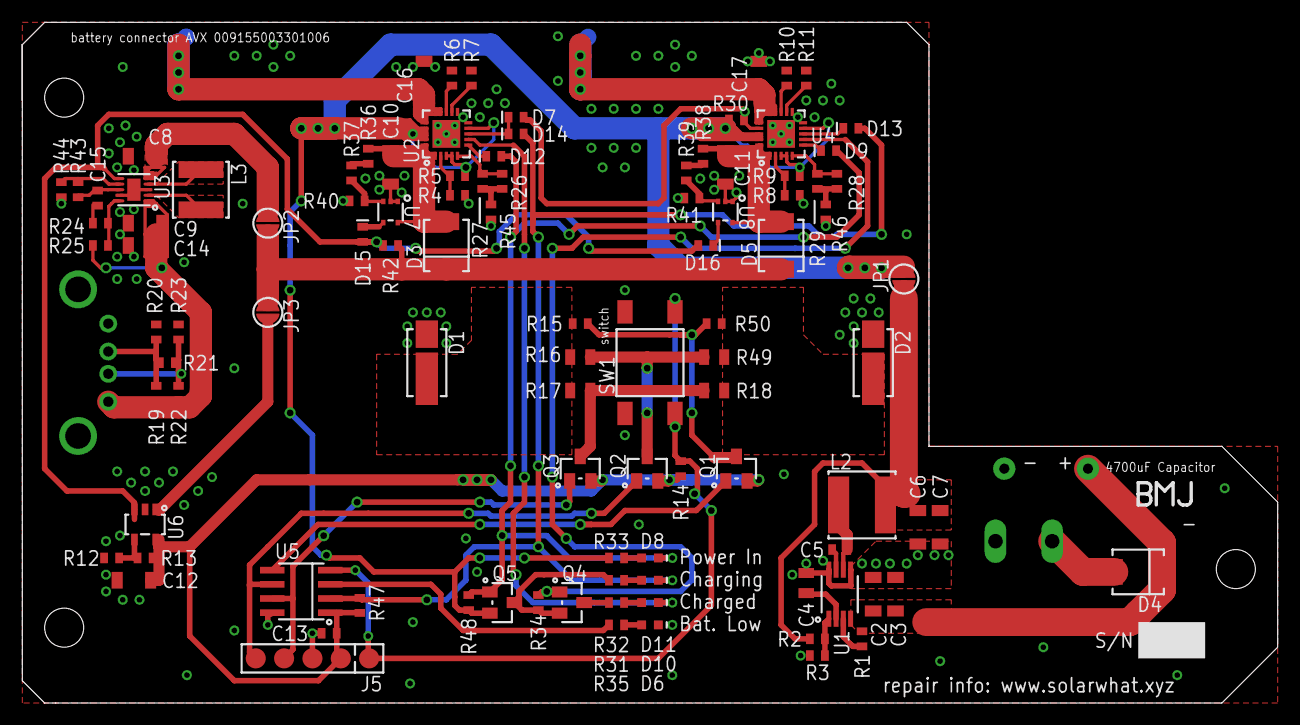
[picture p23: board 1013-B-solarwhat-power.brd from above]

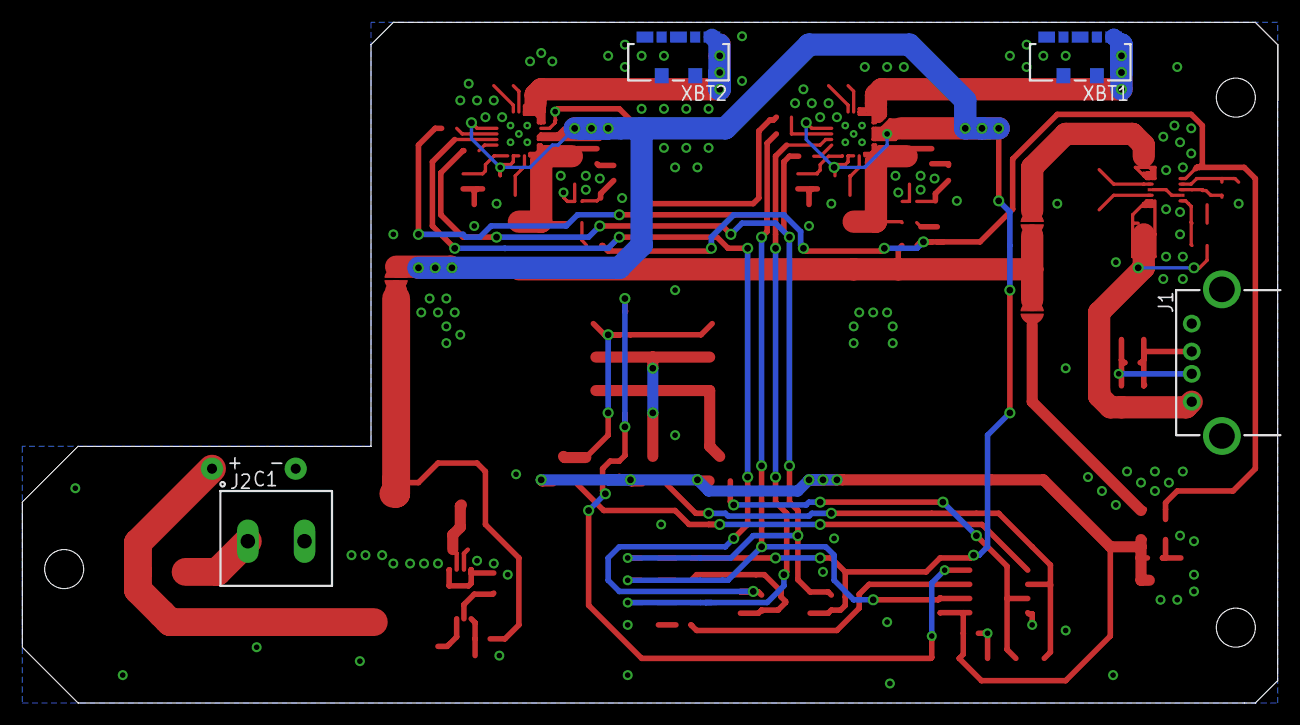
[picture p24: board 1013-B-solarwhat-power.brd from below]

Board: 2 copper layers, 112.5 x 61.0 mm, 115 parts (5 on the bottom side), 69 nets.

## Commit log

2019-09-15 adding pcb files
    adding all pub files in one place for ease of reference
    [1013-B-solarwhat-power-dimensions.dxf, 1013-B-solarwhat-power.brd, 1013-B-solarwhat-power.sch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]
2019-09-15 Create PCB Files
